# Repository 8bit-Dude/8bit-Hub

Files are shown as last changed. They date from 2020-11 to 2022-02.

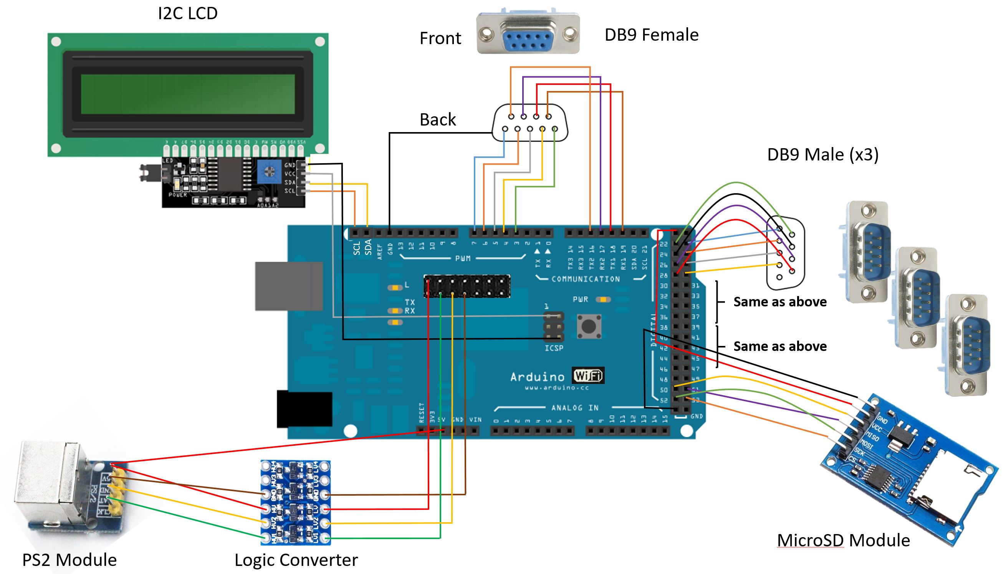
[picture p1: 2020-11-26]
Hardware/Wiring/Overall connection diagram.jpg

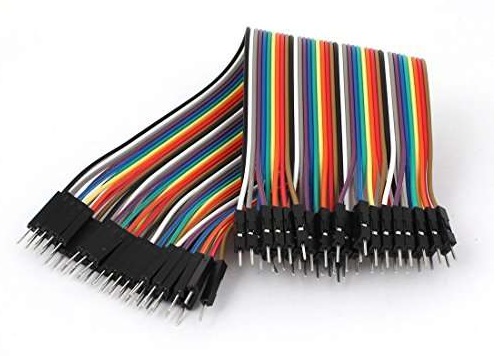
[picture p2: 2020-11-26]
Hardware/Parts List/jump_wire.jpg

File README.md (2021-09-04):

# 8bit-Hub
Firmware and Hardware of the 8bit-Hub, a device for 8bit era computers.

Setting up Arduino IDE to program your 8bit-Hub: 

(1) Clone the Repo @ https://github.com/8bit-Dude/8bit-Hub.git/trunk/Firmware

(2) Install the Arduino IDE

(3) File > Preferences > Sketchbook Location  ---> Set to your local copy of "/Firmware" Folder
    (Restart the Arduino IDE for changes to take effect)

(4) File > Preferences > Additional Boards Manager URLs ---> https://github.com/esp8266/Arduino/releases/download/2.7.4/package_esp8266com_index.json

(5) Tools > Board > Boards Manager ---> search esp8266, then click install

----------------------------------------------------------------------

Flash new sketch (Core Part): 
(Switches set to ON ON ON ON OFF OFF OFF OFF)

(1) Tools > Board > optiboot-avr (in sketchbook) > Arduino Mega 2560 (Optiboot)

(2) Load Hub-Mega2560.ino

(3) Edit the code, for example these lines:

    // Override with some defaults
    if (!strlen(ssid) && !strlen(pswd)) {
        strcpy(ssid, "8bit-Unity");
        strcpy(pswd, "0123456789"); 
    }

(4) Connect Hub to PC, then Tools > Port > Select COM number

(5) Upload sketch

(6) Tools > Serial Monitor ---> Set Baud Rate to 115200

"Et Voila"! You can use the serial monitor to get information/debugging messages.
If you want to revert to "official" firmware, set:  char megaVersion[5] = "v0.1";
The Hub will offer you to download latest firmware (e.g. v0.3) next time you boot.

----------------------------------------------------------------------

Flash new sketch (Wifi Part): 
(Switches set to OFF OFF OFF OFF ON ON ON OFF)

(1) Tools > Board > ESP8266 boards > Generic ESP8266 Module

    Tools > Flash Size > 4MB (FS:2MB OTA:~1019KB)
    
    Tools > Erase Flash > All flash contents

(2) Load Hub-ESP8266.ino and edit code

(3) Connect Hub to PC, then Tools > Port > Select COM number

(4) Upload sketch, "Et Voila"!

Important: Set the switches back to ON ON ON ON OFF OFF OFF OFF after flashing the sketch, otherwise the serial monitor will not work.

----------------------------------------------------------------------

Burning the Optiboot boot loader onto a new board:

2 arduino mega boards are needed for this operation (one is used as progammer).

(1) Connect the boards pins as follows, then connect to USB:

    Programmer:  5V  GND  50  51  52  53
    
      Target:    5V  GND  50  51  52  RST

(2) Tools > Board > Arduino AVR Boards > Arduino Mega or Mega 2560

(3) File > Examples > 11.ArduinoISP > ArduinoISP

(4) Change code as follows:
      #define RESET 10                >  #define RESET 53
      //#define USE_OLD_STYLE_WIRING  >  #define USE_OLD_STYLE_WIRING 
      #define PIN_MOSI	11            >  #define PIN_MOSI 51
      #define PIN_MISO	12            >  #define PIN_MISO 50
      #define PIN_SCK	13            >  #define PIN_SCK  52
      
(5) Sketch > Upload

(6) Tools > Programmer > Arduino as ISP

(7) Tools > Board > optiboot-avr (in sketchbook) > Arduino Mega 2560 (Optiboot)

(8) Tools > Burn Loader, "Et Voila"!

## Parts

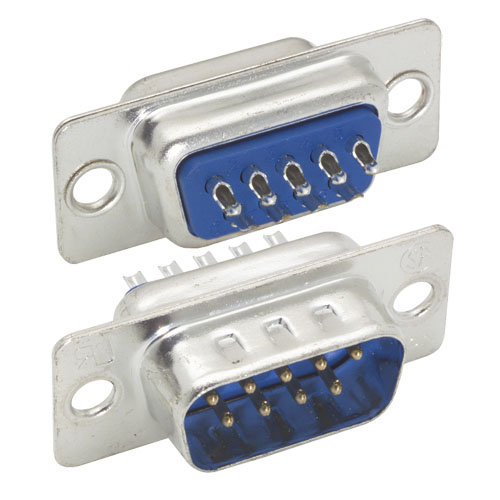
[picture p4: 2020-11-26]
Hardware/Parts List/db9_male.jpg

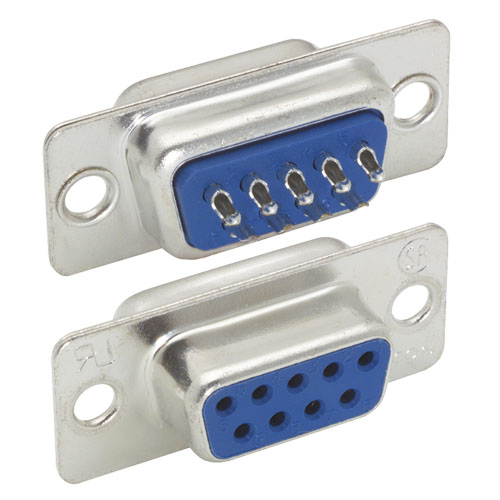
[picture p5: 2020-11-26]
Hardware/Parts List/db9_female.jpg

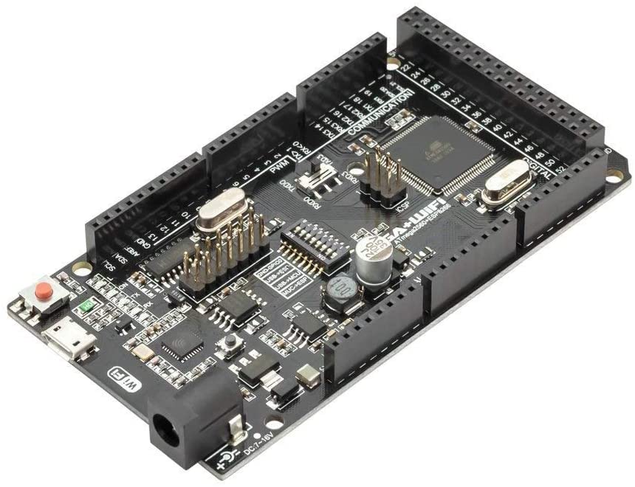
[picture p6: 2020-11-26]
Hardware/Parts List/Arduino.jpg

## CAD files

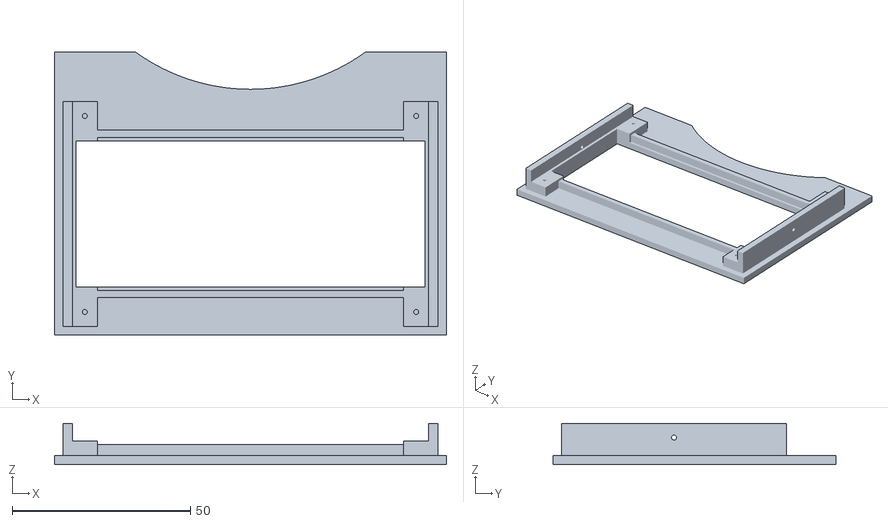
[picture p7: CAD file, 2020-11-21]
Hardware/Drawings/Cover Drawing.stl
110.0 x 79.5 x 11.6

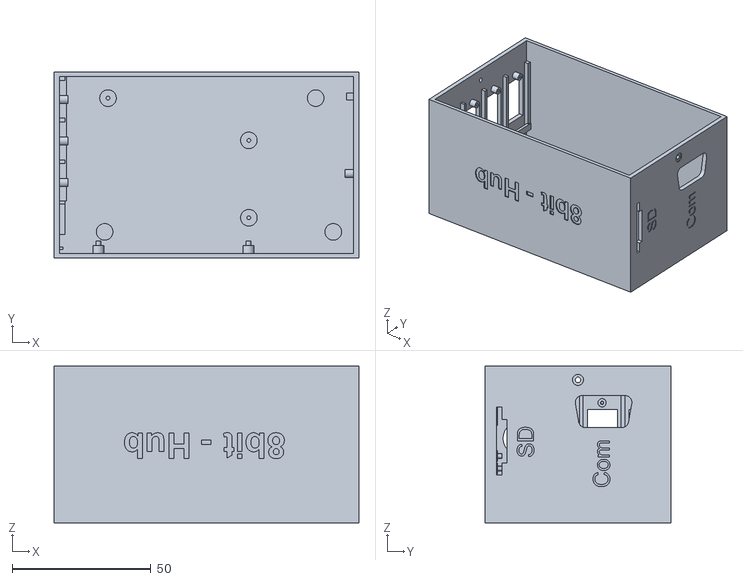
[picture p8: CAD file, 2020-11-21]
Hardware/Drawings/Case Drawing.stl
110.0 x 67.2 x 56.6

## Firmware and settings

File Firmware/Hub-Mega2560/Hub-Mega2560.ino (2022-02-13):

// System libraries
#include <ArduinoOTA.h>
#include <EEPROM.h>
#include <SPI.h>
#include <SD.h>

// Debugging
//#define __DEBUG_JOY__
//#define __DEBUG_JPG__
//#define __DEBUG_MOUSE__
//#define __DEBUG_CMD__
//#define __DEBUG_COM__
//#define __DEBUG_IO__
//#define __DEBUG_PCK__
//#define __DEBUG_TCP__
//#define __DEBUG_UDP__
//#define __DEBUG_URL__
//#define __DEBUG_WEB__

// Firmware Version
char espVersion[5] = "?";
char espUpdate[5] = "?";
char megaVersion[5] = "v0.6";
char megaUpdate[5] = "?";
char urlEsp[]  = "http://8bit-unity.com/Hub-ESP8266.bin";
char urlMega[] = "http://8bit-unity.com/Hub-Mega2560.bin";
char urlVer[]  = "http://8bit-unity.com/Hub-Version.txt";

// HUB Commands
#define HUB_SYS_ERROR     0
#define HUB_SYS_RESET     1
#define HUB_SYS_NOTIF     2
#define HUB_SYS_SCAN      3
#define HUB_SYS_CONNECT   4
#define HUB_SYS_IP        5
#define HUB_SYS_MOUSE     6
#define HUB_SYS_VERSION   7
#define HUB_SYS_UPDATE    8
#define HUB_SYS_STATE     9  // COM 
#define HUB_SYS_RESEND    9  // ESP
#define HUB_DIR_LS       10  // Todo: Implement for root directory /microSD
#define HUB_DIR_MK       11
#define HUB_DIR_RM       12
#define HUB_DIR_CD       13
#define HUB_FILE_OPEN    21
#define HUB_FILE_SEEK    22
#define HUB_FILE_READ    23
#define HUB_FILE_WRITE   24
#define HUB_FILE_CLOSE   25
#define HUB_UDP_OPEN     30
#define HUB_UDP_RECV     31
#define HUB_UDP_SEND     32
#define HUB_UDP_CLOSE    33
#define HUB_UDP_SLOT     34
#define HUB_TCP_OPEN     40
#define HUB_TCP_RECV     41
#define HUB_TCP_SEND     42
#define HUB_TCP_CLOSE    43
#define HUB_TCP_SLOT     44
#define HUB_WEB_OPEN     50
#define HUB_WEB_RECV     51
#define HUB_WEB_HEADER   52
#define HUB_WEB_BODY     53
#define HUB_WEB_SEND     54
#define HUB_WEB_CLOSE    55
#define HUB_URL_GET      60
#define HUB_URL_READ     61

// String definitions
#ifdef __DEBUG_CMD__
  const char* cmdString[] = 
  {"SYS_ERROR","SYS_RESET","SYS_NOTIF", "SYS_SCAN",  "SYS_CONNECT","SYS_IP",   "SYS_MOUSE","SYS_VERSION","SYS_UPDATE","",
   "DIR_LS",   "DIR_MK",   "DIR_RM",    "DIR_CD",    "",           "",         "",         "",           "",          "",
   "FILE_OPEN","FILE_SEEK","FILE_READ", "FILE_WRITE","FILE_CLOSE", "",         "",         "",           "",          "",
   "UDP_OPEN", "UDP_RECV", "UDP_SEND",  "UDP_CLOSE", "UDP_SLOT",   "",         "",         "",           "",          "",
   "TCP_OPEN", "TCP_RECV", "TCP_SEND",  "TCP_CLOSE", "TCP_SLOT",   "",         "",         "",           "",          "",
   "WEB_OPEN", "WEB_RECV", "WEB_HEADER","WEB_BODY",  "WEB_SEND",   "WEB_CLOSE","",         "",           "",          "",
   "URL_GET",  "URL_READ", "",          "",          "",           "",         "",         "",           "",          ""};
#endif
const char* blank = "                    ";
const char* fail  = "Update failed!      ";

// Useful macros
#define MIN(a,b) (a>b ? b : a)
#define MAX(a,b) (a>b ? a : b)

// HUB Modes
#define MODE_NONE  0
#define MODE_APPLE 1
#define MODE_ATARI 2
#define MODE_BBC   3
#define MODE_C64   4
#define MODE_NES   5
#define MODE_ORIC  6
#define MODE_LYNX  7
#define HUB_MODES  8
const char* modeString[HUB_MODES] = {"Please setup", "Apple //", "Atari 8bit", "BBC Micro", "C64/C128", "NES", "Oric", "Lynx"};
byte hubMode = MODE_NONE;

// COMM Params
#define FILES    8     // Number of file handles
#define SLOTS    8     // Number of connection handles
#define PACKET   256   // Max. packet length (bytes)
#define TIMEOUT  1000  // Packet timout (milliseconds)

// HUB Files
File hubFile[FILES];

// IP Params
char IP[17] = "Not connected...";

// Buffers for data exchange with ESP8266
char serBuffer[PACKET];
unsigned char serLen;

////////////////////////////////
//     DEBUGGING functions    //
////////////////////////////////

/*void udpDebug() {
    // Setup request    
    unsigned char cmd[] = {1};

    while (true) {
        writeCMD(HUB_UDP_SLOT);
        writeChar(0);
        writeCMD(HUB_UDP_OPEN);
        writeChar(199); writeChar(47);
        writeChar(196); writeChar(106);
        writeInt(5000); writeInt(5000);
        writeCMD(HUB_UDP_SEND);
        writeBuffer(cmd, 1);
        
        // Wait for answer
        uint32_t timeout = millis()+3000;
        while (millis() < timeout) {
            if (Serial3.find("CMD") && readChar() == HUB_UDP_RECV) {
                readChar();
                if (readBuffer())
                    Serial.print("Received: ");
                    Serial.println(serLen);
                break;
            }
        }
        if (millis() >= timeout) {
              Serial.println("Timeout");
              lcd.print("Timeout");
        }
        writeCMD(HUB_UDP_CLOSE);
        delay(500);
    }
}*/

////////////////////////////////
//      PACKET functions      //
////////////////////////////////

// Define packet structure
typedef struct packet {
    unsigned char ID;
    unsigned char cmd;
    unsigned char slot;  
    unsigned char len;
    unsigned char* data;
    uint32_t timeout;
    struct packet* next;
} packet_t;

packet_t* packetHead = NULL;
unsigned char packetID = 0;

void pushPacket(unsigned char cmd, signed char slot) {
    // Create new packet
    packet_t* packet = malloc(sizeof(packet_t));
    packet->next = NULL;

    // Assign ID & Timeout
    if (++packetID>254) { packetID = 1; }
    packet->ID = packetID;
    packet->timeout = millis() + TIMEOUT;

    // Copy data to packet
    packet->len = serLen;
    packet->cmd = cmd;
    packet->slot = slot;
    packet->data = (unsigned char*)malloc(serLen);
    memcpy(packet->data, serBuffer, serLen);
    
    // Append packet at tail of linked list
    if (!packetHead) {
        packetHead = packet;
    } else {
        packet_t *packetTail = packetHead;
        while (packetTail->next != NULL) {
            packetTail = packetTail->next;
        }
        packetTail->next = packet;
    }
#ifdef __DEBUG_PCK__
    Serial.print("PUSH: "); Serial.println((byte)packet->ID);
#endif
}

packet_t *getPacket(unsigned char cmd, signed char slot) {
    // Find packet with matching cmd/slot
    packet_t *packet = packetHead;
    while (packet) {
        if (packet->cmd == cmd && packet->slot == slot)
            return packet;
        packet = packet->next;
    }
    return NULL;
}

void popPacket(unsigned char ID) {
    // Pop packet with matching ID
    packet_t *prev = NULL, *next = NULL, *packet = packetHead;
    while (packet) {
        next = packet->next;
        if (packet->ID == ID) {
            if (prev)
                prev->next = next;
            else
                packetHead = next;
        #ifdef __DEBUG_PCK__
            Serial.print("POP: "); Serial.println((byte)packet->ID);    
        #endif
            free(packet->data);
            free(packet);
            return;
        }
        prev = packet;
        packet = next;
    }
}

void packetTimeout() {
  // Remove packets that have exceeded timeout
  while (packetHead && millis() > packetHead->timeout) {
      popPacket(packetHead->ID);
  }
}

//////////////////////////
//    List functions    //
//////////////////////////

// Define list structure
typedef struct list {
    char* data;
    struct list* next;
} list_t;

list_t* listHead;

void pushList(char* data) {
    // Create new packet
    list_t* elt = malloc(sizeof(list_t));
    elt->data = data;
    elt->next = NULL;

    // Append packet at tail of linked list
    if (!listHead) {
        listHead = elt;
    } else {
        list_t *tail = listHead;
        while (tail->next != NULL) {
            tail = tail->next;
        }
        tail->next = elt;
    }     
}

unsigned char* getList(unsigned char index) {
    byte i=0;
    list_t* elt = listHead;
    while (elt && i<index) {
        elt = elt->next;
        i++;
    }
    if (elt) {
        return elt->data;
    } else {
        return NULL;
    }
}

unsigned char lenList() {
    byte i=0;
    list_t* elt = listHead;
    while (elt) {
        elt = elt->next;
        i++;
    }
    return i;    
}

void clearList() {
    list_t* elt;
    while (listHead) {
        elt = listHead;
        listHead = elt->next;
        free(elt);
    }
}

////////////////////////////////
//    PERIPHERAL functions    //
////////////////////////////////

// Joystick states
#define JOY_UP    1
#define JOY_DOWN  2
#define JOY_LEFT  4
#define JOY_RIGHT 8
#define JOY_FIRE1 16
#define JOY_FIRE2 32

// Joystick modes
#define JOY_STD  0
#define JOY_PASE 1

// Joystick params
unsigned char joyMode = JOY_STD;
unsigned char joyState[4] = { 255, 255, 255, 255 };
unsigned char joyPins[4][8] = { { 23, 25, 27, 29, 22, 24, 28, 26 },   // U, D, L, R, F1, F2, Alt F2, GND
                                { 31, 33, 35, 37, 30, 32, 36, 34 },
                                { 39, 41, 43, 45, 38, 40, 44, 42 },
                                {  0,  0,  0,  0,  0,  0,  0,  0 } }; // Joy #4 unassigned in current version
unsigned char joyStnd[6] = {   1,  2,  4,  8, 16, 32 };
unsigned char joyPase[6] = {  16,  8,  1,  2,  4,  0 };

// Mouse params
unsigned char mouseState[2] = { 255, 255 };
unsigned char mouseSpeed = 1;
unsigned char mouseFPS = 1;

void setupJOY() {
    // Set I/O pins
    for (byte i=0; i<3; i++) {
        for (byte j=0; j<7; j++) {
            pinMode(joyPins[i][j], INPUT_PULLUP);  // Inputs
        }
        pinMode(joyPins[i][7], OUTPUT);            // Ground
        digitalWrite(joyPins[i][7], LOW);
    }  

    // Be careful with Atari 7800 joypads (Pin 9 causes short-circuit)
    for (byte i=0; i<3; i++) { 
        if (!digitalRead(joyPins[i][6])) joyPins[i][6] = joyPins[i][5];
    }
}

void readJOY() {
    // Read digital pins
    switch (joyMode) {
    case JOY_STD:    
        for (byte i=0; i<3; i++) { 
            joyState[i] |= 63;
            for (byte j=0; j<6; j++) {
                if (!digitalRead(joyPins[i][j])) { joyState[i] &= ~joyStnd[j]; }  
            } 
            if (!digitalRead(joyPins[i][6])) { joyState[i] &= ~joyStnd[5]; } 
        }  
        break;
    case JOY_PASE:
        for (byte i=0; i<2; i++) { 
            joyState[i] = 32;
            for (byte j=0; j<6; j++) {
                if (digitalRead(joyPins[i][j])) { joyState[i] += joyPase[j]; }  
            }
            if (!digitalRead(joyPins[i][6])) { joyState[i] &= ~joyPase[5]; } 
        }
        break;
    }
#ifdef __DEBUG_JOY__
    Serial.print("Joystick: "); 
    for (byte i=0; i<4; i++) { Serial.println(joyState[i]); Serial.print(","); }
#endif    
}

void readMouse() {
    unsigned char s = readChar();
    signed char x = readChar();
    signed char y = readChar();
    signed char w = readChar();

    // Adjust inputs
    switch (mouseSpeed) {
    case 0:
        x /= 6; y /= -4;
        break;
    case 1:
        x /= 4; y /= -3;
        break;
    default:
        x /= 2; y /= -2;
      break;        
    }
    if (w == -128) w = 0;

    // Register inputs
    joyState[0] |= 192; joyState[1] |= 192; joyState[2] |= 192;
    if (s&1) { joyState[0] &= ~64;  }  // L Button
    if (s&2) { joyState[0] &= ~128; }  // R Button
    if (s&4) { joyState[1] &= ~64;  }  // M Button
    if (w<0) { joyState[2] &= ~64;  }  // W Up
    if (w>0) { joyState[2] &= ~128; }  // W Down
    if ((x!=0 || y!=0) && (mouseState[0]==255 || mouseState[1] ==255)) {
      mouseState[0] = 80; mouseState[1] = 100;
    }
    if (x<0) { mouseState[0] -= MIN(mouseState[0], -x);    }
    if (x>0) { mouseState[0] += MIN(159-mouseState[0], x); }
    if (y<0) { mouseState[1] -= MIN(mouseState[1], -y);    }
    if (y>0) { mouseState[1] += MIN(199-mouseState[1], y); }
#ifdef __DEBUG_MOUSE__   
    Serial.print("M:"); Serial.print((s&1)>0); // L but
    Serial.print(",");  Serial.print((s&4)>2); // M but
    Serial.print(",");  Serial.print((s&2)>1); // R but
    Serial.print(",");  Serial.print(mouseState[0]);
    Serial.print(",");  Serial.print(mouseState[1]);
    Serial.print(",");  Serial.println(w);
#endif    
}

////////////////////////////////
//        SD functions        //
////////////////////////////////

unsigned char sdInserted = 0;

void printDir(File dir, int numTabs) {
    while (true) {
        File entry =  dir.openNextFile();
        if (!entry) {
          // no more files
          break;
        }
        for (uint8_t i=0; i<numTabs; i++) {
          Serial.print('\t');
        }
        Serial.print(entry.name());
        if (entry.isDirectory()) {
          Serial.println("/");
          printDir(entry, numTabs+1);
        } else {
          // files have sizes, directories do not
          Serial.print("\t\t");
          Serial.println(entry.size(), DEC);
        }
        entry.close();
    }
}

void setupSD() {  
    // Try to init SD card
    Serial.println("Initializing SD card...");
    if (!SD.begin(53)) {
        Serial.println("Notif: No Micro-SD card inserted");
        sdInserted = 0;
        return;
    }
    
    // Open root folder
    File root = SD.open("/");
    sdInserted = 1;

    // Debugging
    //decodeJPG("banner.jpg");    
    //printDir(root, 1); 
}

////////////////////////////////
//        LCD functions       //
////////////////////////////////

#include <LiquidCrystal_I2C.h>

LiquidCrystal_I2C lcd(0x27,2,1,0,4,5,6,7);

void setupLCD() {
    // Setup LCD light
    lcd.begin(20,4);
    lcd.setBacklightPin(3,POSITIVE);
    lcd.setBacklight(HIGH);
    displayHeader();
}

void displayHeader() {
    // Show header
    lcd.clear();
    lcd.setCursor(0,0);
    lcd.print("    < 8bit-Hub >");
}

void displayMode() {
    lcd.setCursor(0,1);
    lcd.print("Mode:               ");
    lcd.setCursor(5,1);
    lcd.print(modeString[hubMode]);
    Serial.print("Hub Mode: ");
    Serial.println(modeString[hubMode]);    
}

void displaySD() {
    lcd.setCursor(0,2);
    lcd.print("SD:");
    if (sdInserted) {
        lcd.print("Inserted");
    } else {
        lcd.print("Not inserted");
    }
}

void displayIP() {
    lcd.setCursor(0,3);
    lcd.print("IP:                 ");
    lcd.setCursor(3,3);
    lcd.print(IP);
}

//////////////////////
//    COM Packets   //
//////////////////////

#define COM_ERR_OK      0
#define COM_ERR_NODATA  1
#define COM_ERR_HEADER  2 
#define COM_ERR_TRUNCAT 3
#define COM_ERR_CORRUPT 4
#define COM_ERR_RESENT  5
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
void loop() { 
    // Check packets time-out
    packetTimeout();

    // Check Joysticks states
    readJOY(); 
      
    // Process commands from ESP8266
    if (Serial3.find("CMD")) 
        espProcessCMD();

    // Process COM I/O
    if (hubMode == MODE_LYNX) {
        // Process Lynx Communication (asynchronously)
        lynxProcessCOM();      
    } else    
    if (hubMode == MODE_ATARI || hubMode == MODE_C64 || hubMode == MODE_NES || hubMode == MODE_ORIC) {
        // Check if data burst stalled (allow extra time for VBI/DLI interrupts)
        if (interruptOffset && (millis()-interruptTimer) > 5) {
            interruptOffset = 0; 
            hasHeader = 0;
            inByte = 0;
            if (hubMode == MODE_ATARI)
                PORTH |= _BV(PH3);   // Pin 4 HIGH == READY
            if (hubMode == MODE_C64)
                PORTH &= ~_BV(PH1);  // Pin 16 LOW   
            if (hubMode == MODE_NES)    
                PORTH &= ~_BV(PH3);  // Pin 6 HIGH (inverted) 
        #ifdef __DEBUG_IO__  
            if (interruptMode)              
                inSta++;
            else
                outSta++;
        #endif    
        } 
    }

    // Display transfer rate
#ifdef __DEBUG_IO__
    if (millis()-timerIO > 5000) {
        timerIO = millis();
        Serial.print(" Rate: in=");
        Serial.print(inRec/5); Serial.print("b/s, out=");
        Serial.print(outRec/5); Serial.print("b/s, err(in)=");
        Serial.print(inErr); Serial.print(", stall(in)=");
        Serial.print(inSta); Serial.print(", stall(out)=");
        Serial.println(outSta); 
        inRec = 0; inErr = 0; inSta = 0; 
        outRec = 0; outSta = 0;
    } 
#endif
    
    // Display COM Stats
#ifdef __DEBUG_COM__
    if (comCode != COM_ERR_NODATA) {
        comErr[comCode] += 1;
        Serial.print(" (RX)");
        Serial.print(" ID=");  Serial.print(comInID);
        Serial.print(" Len="); Serial.print(comInLen);
        Serial.print(" (TX)");
        Serial.print(" ID=");  Serial.print(comOutID);
        Serial.print(" Len="); Serial.print(comOutLen);
        Serial.print(" (ERR)");        
        Serial.print(" Head="); Serial.print(comErr[COM_ERR_HEADER]);
        Serial.print(" Trnc="); Serial.print(comErr[COM_ERR_TRUNCAT]);
        Serial.print(" Crpt="); Serial.print(comErr[COM_ERR_CORRUPT]);
        Serial.print(" Rsnt="); Serial.println(comErr[COM_ERR_RESENT]);
    }
#endif
}

////////////////////////////////
//        JPG functions       //
////////////////////////////////
/*

#include <picojpeg.h>

const unsigned char lynxPaletteR[] = {165,  66,  66,  49,  49,  33,  33, 115, 231, 247, 247, 214, 132, 247, 132, 0};
const unsigned char lynxPaletteG[] = { 16,  49, 132, 198, 198, 132,  82,  82, 115, 231, 148,  49,  33, 247, 132, 0};
const unsigned char lynxPaletteB[] = {198, 181, 198, 198,  82,  33,  82,  33,  82,   0, 165,  66,  66, 247, 132, 0};

File jpgFile;
unsigned int jpgSize, jpgOfs;

uint8_t callbackJPG(uint8_t* pBuf, uint8_t buf_size, uint8_t *pBytes_actually_read, void *pCallback_data) {
    unsigned int n = MIN(jpgSize - jpgOfs, buf_size);
    *pBytes_actually_read = (uint8_t)(n);
    jpgFile.read(pBuf,n);
    jpgOfs += n;
    return 0;    
}

void decodeJPG(unsigned char* filename) {
    // Open file from SD card
    uint32_t timer = millis();     

    // Open jpeg file from SD card
    jpgFile = SD.open(filename, FILE_READ);
    jpgSize = jpgFile.size();
    jpgOfs = 0;

    // Initialize decoder
    pjpeg_image_info_t jpgInfo;
    unsigned char status = pjpeg_decode_init(&jpgInfo, callbackJPG, NULL, 0);
    if (status) {
      Serial.print("pjpeg_decode_init() failed with status ");
      Serial.println(status);
      if (status == PJPG_UNSUPPORTED_MODE) {
        Serial.println("Progressive JPEG files are not supported.");
      }
      return;
    }
    
    // Open cache file to store decoded image
    if (SD.exists("cache")) { SD.remove("cache"); }
    File cacheFile = SD.open("cache", FILE_WRITE);
    
    // Scanning variables
    unsigned int xElt, yElt;
    unsigned char xElt8, yElt8;
    unsigned char xMin, xMax, yMin, yMax;
    unsigned int palDist, palMini;
    unsigned char palIndex;
    unsigned char bmp[9][82];

    // Scan through block rows
    for (unsigned int yMCU=0; yMCU<jpgInfo.m_height; yMCU+=jpgInfo.m_MCUHeight) {

        // Computer's Y coordinate range
        yMin = (102 * (yMCU                    )) / jpgInfo.m_height;
        yMax = (102 * (yMCU+jpgInfo.m_MCUHeight)) / jpgInfo.m_height;
        yMax = MIN(yMax, 102);

        // Reset bmp array
        for (unsigned int y=yMin; y<yMax; y++) {
            bmp[y-yMin][0] = 0x52;
            memset(&bmp[y-yMin][1], 0, 81);
        }

        // Scan through block cols
        for (unsigned int xMCU=0; xMCU<jpgInfo.m_width; xMCU+=jpgInfo.m_MCUWidth) {

            // Computer's X coordinate range
            xMin = (160 * (xMCU                   )) / jpgInfo.m_width;
            xMax = (160 * (xMCU+jpgInfo.m_MCUWidth)) / jpgInfo.m_width;
            xMax = MIN(xMax, 160);

            // Decode this block
            pjpeg_decode_mcu();
    
            // Scan Y coordinate range
            for (unsigned int y=yMin; y<yMax; y++) {
                yElt = (y * jpgInfo.m_height)/102 - yMCU;  yElt8 = yElt/8;
                //Serial.print((byte)y); Serial.print(": ");
    
                // Scan X coordinate range
                for (unsigned int x=xMin; x<xMax; x++) {
                    xElt = (x * jpgInfo.m_width)/160 - xMCU;  xElt8 = xElt/8;
                    //Serial.print((byte)x); Serial.print(", ");
    
                    // Compute offset of element
                    unsigned int block_ofs = (xElt8 * 8U) + (yElt8 * 16U);
                    unsigned int elt_oft = 8*(yElt%8) + (xElt%8);
                    const uint8_t *pSrcR = jpgInfo.m_pMCUBufR + block_ofs + elt_oft;
                    const uint8_t *pSrcG = jpgInfo.m_pMCUBufG + block_ofs + elt_oft;
                    const uint8_t *pSrcB = jpgInfo.m_pMCUBufB + block_ofs + elt_oft;
    
                    // Find matching palette color
                    palMini = 3*256;
                    for (byte i=0; i<16; i++) {
                        palDist = abs(lynxPaletteR[i] - *pSrcR) + abs(lynxPaletteG[i] - *pSrcG) + abs(lynxPaletteB[i] - *pSrcB);
                        if (palDist<palMini) {
                            palIndex = i; 
                            palMini = palDist;
                        }
                    }

                    // Save to bmp buffer
                    bmp[y-yMin][x/2+1] |= palIndex << (4*((x+1)%2));
                    //Serial.print(palIndex); Serial.print(",");                
                }
                //Serial.println();
            }
            //Serial.println();
        }

        // Write to char file
        cacheFile.write(&bmp[0][0], 82*(yMax-yMin));
    }

    // Close files
    cacheFile.write((byte)0x00);
    cacheFile.close();  
    jpgFile.close();
#ifdef __DEBUG_JPG__ 
    Serial.println(F("JPEG image info"));
    Serial.print("Width      : "); Serial.println(jpgInfo.m_width);
    Serial.print("Height     : "); Serial.println(jpgInfo.m_height);
    Serial.print("Scan type  : "); Serial.println(jpgInfo.m_scanType);
    Serial.print("MCU/row    : "); Serial.println(jpgInfo.m_MCUSPerRow);
    Serial.print("MCU/col    : "); Serial.println(jpgInfo.m_MCUSPerCol);
    Serial.print("MCU/width  : "); Serial.println(jpgInfo.m_MCUWidth);
    Serial.print("MCU/height : "); Serial.println(jpgInfo.m_MCUHeight);
    Serial.print("Render time: "); Serial.print(millis()-timer); Serial.println(" ms");
#endif  
}
*/

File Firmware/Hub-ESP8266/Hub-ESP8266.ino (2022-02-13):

  
// System libraries
#include <FS.h>
#include <ps2mouse.h>
#include <ESP8266WiFi.h>
#include <ESP8266HTTPClient.h>
#include <ESP8266httpUpdate.h>
#include <WiFiClient.h>
#include <WiFiUdp.h>

// Debugging
//#define __DEBUG_WIFI__

// Firmware Version
char espVersion[] = "v0.6";

// HUB Commands
#define HUB_SYS_ERROR     0
#define HUB_SYS_RESET     1
#define HUB_SYS_NOTIF     2
#define HUB_SYS_SCAN      3
#define HUB_SYS_CONNECT   4
#define HUB_SYS_IP        5
#define HUB_SYS_MOUSE     6
#define HUB_SYS_VERSION   7
#define HUB_SYS_UPDATE    8
#define HUB_SYS_RESEND    9
#define HUB_DIR_LS       10
#define HUB_DIR_MK       11
#define HUB_DIR_RM       12
#define HUB_DIR_CD       13
#define HUB_FILE_OPEN    21
#define HUB_FILE_SEEK    22
#define HUB_FILE_READ    23
#define HUB_FILE_WRITE   24
#define HUB_FILE_CLOSE   25
#define HUB_UDP_OPEN     30
#define HUB_UDP_RECV     31
#define HUB_UDP_SEND     32
#define HUB_UDP_CLOSE    33
#define HUB_UDP_SLOT     34
#define HUB_TCP_OPEN     40
#define HUB_TCP_RECV     41
#define HUB_TCP_SEND     42
#define HUB_TCP_CLOSE    43
#define HUB_TCP_SLOT     44
#define HUB_WEB_OPEN     50
#define HUB_WEB_RECV     51
#define HUB_WEB_HEADER   52
#define HUB_WEB_BODY     53
#define HUB_WEB_SEND     54
#define HUB_WEB_CLOSE    55
#define HUB_URL_GET      60
#define HUB_URL_READ     61

// ESP Params
#define SLOTS    8     // Number of tcp/udp handles
#define PACKET   256   // Max. packet length (bytes)
#define TIMEOUT  10000 // Wifi connection timeout (msec)

// Wifi connection params
char ssid[32], pswd[64];

// Buffers for data exchange
char serBuffer[PACKET], serLen;

// ESP8266 settings
IPAddress tcpIp[SLOTS];
IPAddress udpIp[SLOTS];
unsigned int tcpPort[SLOTS];
unsigned int udpPort[SLOTS];
unsigned int webPort;
WiFiClient tcp[SLOTS];
WiFiUDP    udp[SLOTS];
WiFiServer webServer(80); 
WiFiClient webClient;
HTTPClient urlClient;
char udpSlot=0, tcpSlot=0;
uint32_t webTimer, webTimeout;
boolean webBusy = false;

// UDP/TCP socket management
uint32_t socketTimer = 0;
unsigned char socketPeriod = 10;
unsigned char socketTimeout = 10;

// Mouse Setting
PS2Mouse mouse(0, 2);
unsigned char mousePeriod = 0;
long mouseTimer = 0;

////////////////////////////////
//      PACKET functions      //
////////////////////////////////

// Define packet structure
typedef struct packet {
    unsigned char cmd;
    signed char slot;
    unsigned char len;
    char buffer[PACKET];
} packet_t;

packet_t lastPacket;

////////////////////////////
//      UDP functions     //
////////////////////////////

void udpOpen(unsigned char slot) {
    // Get data from Mega
    unsigned char ip1, ip2, ip3, ip4;
    unsigned int listenPort;
    ip1 = readChar(); ip2 = readChar();
    ip3 = readChar(); ip4 = readChar();
    udpIp[slot] = IPAddress(ip1, ip2, ip3, ip4);
    readInt(&udpPort[slot]);
    readInt(&listenPort);  

    // Open UDP port
    if (!udp[slot].begin(listenPort))
        reply(HUB_SYS_ERROR, "UDP connection failed");  
}

void udpReceive(unsigned char slot) {
    // Check for incoming packet
    int len = udp[slot].parsePacket();
    if (len) {
        // Wait for all data to arrive (within timeout period)
        uint32_t timeOut = millis()+socketTimeout;
        while (true) {
            if (udp[slot].available() == len) break;
            if (millis() > timeOut) return;
        }

        // Read UDP packet
        len = udp[slot].read(serBuffer, PACKET-1);
        if (len) {
            // Send to mega        
            serLen = len; serBuffer[serLen] = 0;
            writePacket(HUB_UDP_RECV, slot, serBuffer, serLen);
        }
    }
}

void udpSend(unsigned char slot) {
    serLen = readBuffer(serBuffer);
    udp[slot].beginPacket(udpIp[slot], udpPort[slot]);
    udp[slot].write(serBuffer, serLen);
    udp[slot].endPacket();
}

void udpClose(unsigned char slot) {
    udp[slot].stop();
}

////////////////////////////
//      TCP functions     //
////////////////////////////

boolean tcpConnect(unsigned char slot) {
    // Open TCP connection
    if (tcp[slot].connect(tcpIp[slot], tcpPort[slot])) {
        tcp[slot].setNoDelay(true);
        tcp[slot].keepAlive(7200, 75, 9);
        return true;
    } else {
        return false;
    }
}

void tcpOpen(unsigned char slot) {            
    // Get data from Mega
    unsigned char ip1, ip2, ip3, ip4;
    ip1 = readChar(); ip2 = readChar();
    ip3 = readChar(); ip4 = readChar();
    tcpIp[slot] = IPAddress(ip1, ip2, ip3, ip4);
    readInt(&tcpPort[slot]); 
    if (!tcpConnect(slot)) 
        reply(HUB_SYS_ERROR, "TCP connection failed");
}

void tcpReceive(unsigned char slot) {
    if (tcp[slot].available()) {
        // Read data from TCP
        serLen = tcp[slot].read((unsigned char*)serBuffer, PACKET-1);
        serBuffer[serLen] = 0;
        
        // Send it to mega        
        writePacket(HUB_TCP_RECV, slot, serBuffer, serLen);                
    }
}

void tcpSend(unsigned char slot) {
    // Get data and try to send over TCP
    serLen = readBuffer(serBuffer);
    if (!tcp[slot].connected()) 
        if (!tcpConnect(slot))
            return;
    tcp[slot].write(serBuffer, serLen);
}

void tcpClose(unsigned char slot) {
    if (tcp[slot].connected())
        tcp[slot].stop(); 
}

////////////////////////////
//      WEB functions     //
////////////////////////////

void webOpen() {            
    webBusy = false;
    readInt(&webPort); 
    readInt(&webTimeout);
    webServer.begin(webPort);
}
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

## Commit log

2020-09-12 Support libraries for compilation in Arduino IDE.
2020-09-23 Cleaned-up code, fixed minor COM bug.
    [Hub-Mega2560.ino]
2020-09-30 Fixed issue with TCP connections not staying alive.
    [Hub-ESP8266.ino, Hub-Mega2560.ino]
2020-09-30 Fixed bugs in serial communication and web serving.
    [Hub-ESP8266.ino, Hub-Mega2560.ino]
2020-10-07 Fixed naming from HTTP to URL (for consistency with IP65)
    [Hub-ESP8266.ino, Hub-Mega2560.ino]
2020-10-24 Reduced TCP/UDP slots and added timer for checking incoming TCP/UDP packets. (This should prevent flooding the ESP with parsing requests)
    [Hub-ESP8266.ino]
2020-10-24 Reduced TCP/UDP slots and added timer for checking incoming TCP/UDP packets. Fixed SSID scan function, and input box for SSID/PASS longer than 15 chars. Fixed detection of resent packets from COM.
    [Hub-Mega2560.ino]
2020-10-24 Fixes to default mouse state, and reply to resent packets.
    [Hub-Mega2560.ino]
2020-11-15 Fixed issue of packets being sometime sent only partially from ESP to MEGA (i.e. for now: resend the packet)
    [Hub-ESP8266.ino, Hub-Mega2560.ino]
2020-11-15 Added Optiboot Board (needed for upload to Mega)
    [arduino_zero.cfg]
2020-11-21 Added STL files of the 8bit-Hub Case.
    [Case Drawing.stl, Cover Drawing.stl]
2020-11-21 Updated to more performant PS2 library (with IntelliMouse extension for the wheel!)
2020-11-26 Added Tutorial on Programming the MEGA2560+ESP8266 Board.
2020-11-26 Added wiring of COM cables.
2022-01-07 ESP Firmware Update 0.5: Minor fix to Wifi connection routine.
    [Hub-ESP8266.ino]
2022-02-23 Added CC65 based sample code for 8bit-Hub
    [lynx.cfg, oric.cfg]
2022-02-23 Minor changes to CC65 sample code.
